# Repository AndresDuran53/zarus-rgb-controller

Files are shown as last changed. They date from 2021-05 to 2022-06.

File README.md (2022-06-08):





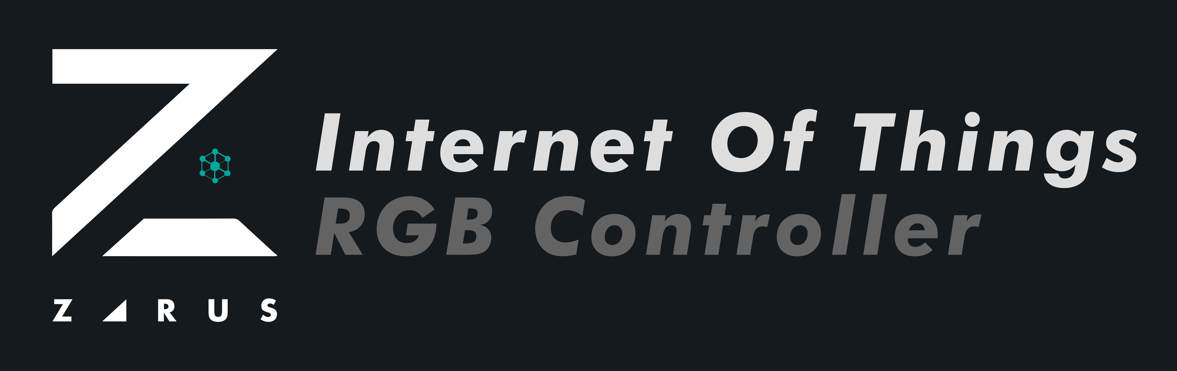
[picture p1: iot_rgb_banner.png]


# RGB Strip Controller for ESP8266 and ESP32
Control your rgb lights from your cell phone, using a website, an mqtt broker, or even the same remote control that came with the lights

Look at the [Zarus IoT Hub](https://github.com/AndresDuran53/zarus-iot-app) to get an easy way to connect to the devices without an IP.

## Quick Start
### Using Zarus IoT Hub application (Android only)
1. Download the Zarus IoT Hub application and open it.
2. Go to the *Devices* tab and click on *Find new device*.
3. Click on the device that you want to configure and wait until your phone connects.
4. Insert the name and password of your Home Wi-Fi, and click *Save configuration*.
5. Connect your phone again to your Home Wi-Fi and click *Refresh*.
6. Click *Scan network* and click the device that you want to add.
7. Now you can go to the *Home* tab and click the device to start using you new device.

For more information go to [Zarus IoT Hub](https://github.com/AndresDuran53/zarus-iot-app)

### Manually using a browser (IOS - Android - PC)
1. Go to your Wi-Fi configuration and look for a network named like: "rgb-light-xxxxxx"
2. Connect to that network with the password: *password123*
3. Open a browser (Google Chrome, Firefox, etc...) and go to *http://192.168.4.1*
4. On the WebPage click on *Settings* and *Device Settings*
5. Insert the SSID (name) and password of your Wi-Fi which you want the device be connected to, and click *Save/Guardar*.
6. Disconnect from the device network and connect to your Wi-Fi
7. You have to find which IP your device has in your network, you can use different applications for that.
8. Now that you have the IP of your device you just have to put that IP into the browser and you are going to be able to control the device.

## Create yours from scratch
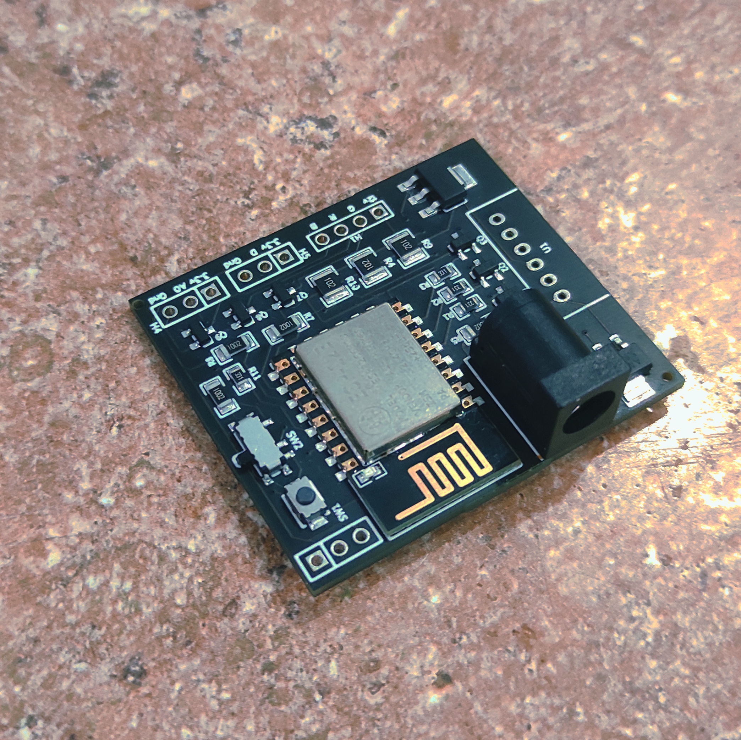
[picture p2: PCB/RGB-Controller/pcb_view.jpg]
RGB controller PCB view
[](PCB/RGB-Controller/pcb_view.jpg)

### PCB creation
You can find the Gerber, BOM, and PickAndPlace files in the [PCB/RGB-Controller](PCB/RGB-Controller) folder, to create your own PCB. Also you can import the hole folder into [EasyEDA](https://easyeda.com/es) to modify it yourself.

You only need to add a cable to connect to the RGB Leds (5050 Strip or NeoPixel, respective paths), and the InfraRed transistor if you wanted.

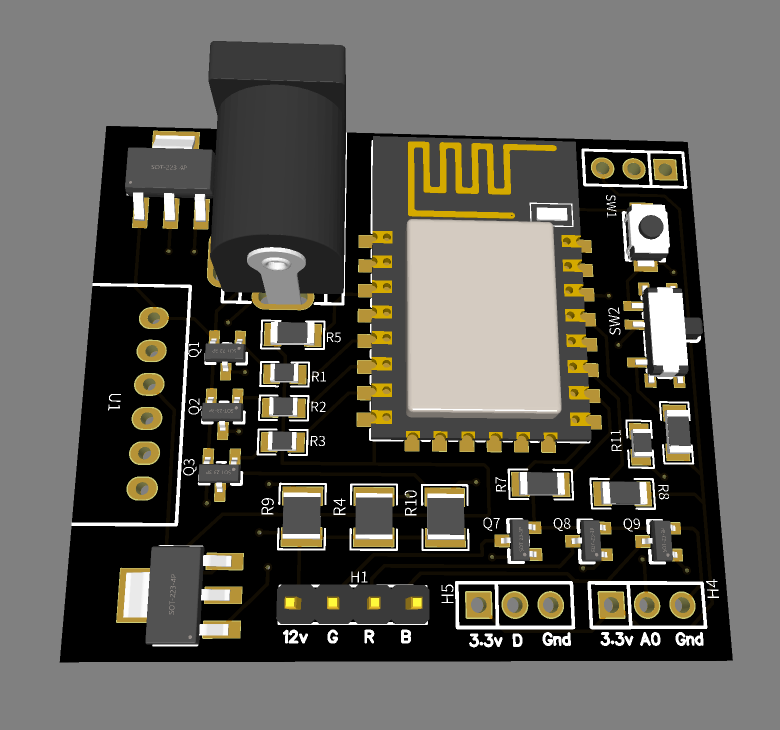
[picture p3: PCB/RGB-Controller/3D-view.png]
RGB controller PCB 3D view
[](PCB/RGB-Controller/3D-view.png)

### 3D Printing
In the folder [3D Desing](3D%20Desing) you can find the .stl file to print in any 3D printer and also a .FCStd file that you can use to modify the model using [Freecad](https://www.freecadweb.org/). Or if you wanted you can use the .gcode to just import to a printer.

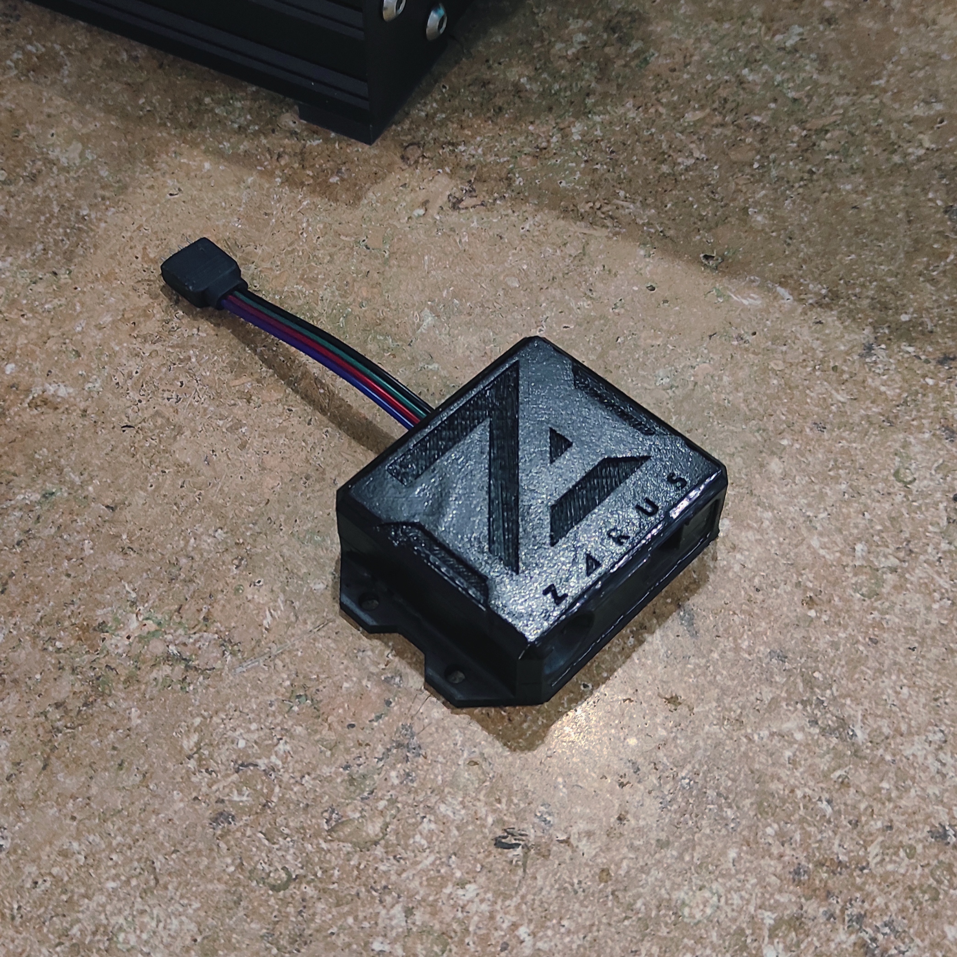
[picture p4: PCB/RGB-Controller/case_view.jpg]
RGB controller 3D case
[](PCB/RGB-Controller/case_view.jpg)

#### Parameters used for gcode
* Printer: Ender 3 Pro
* Material: PETG
* Heat Bed: Yes

### Compile using Arduino
1. Download the firmware in [RGB-Strip-Firmware](RGB-Strip-Firmware).
2. Open it in the Arduino IDE.
3. Import the libraries.
4. Upload the sketch.

#### Libraries and tools needed
Tools for upload files into the ESP device:
* ESP8266: [ESP8266fs](https://github.com/esp8266/arduino-esp8266fs-plugin/releases) | ESP32: [ESP32FS](https://github.com/me-no-dev/arduino-esp32fs-plugin/releases)

Libraries:
* [Network Controller](https://github.com/AndresDuran53/zarus-network-controller/)
* [IRremoteESP8266](https://github.com/crankyoldgit/IRremoteESP8266)

## TO-DO
- [ ] Check the IRremote library for ESP32

## License
Zarus RGB Controller is an open source code. All files are licenced under Creative Commons [Reconocimiento-NoComercial-CompartirIgual 4.0 Internacional](https://creativecommons.org/licenses/by-nc-sa/4.0/deed.es)

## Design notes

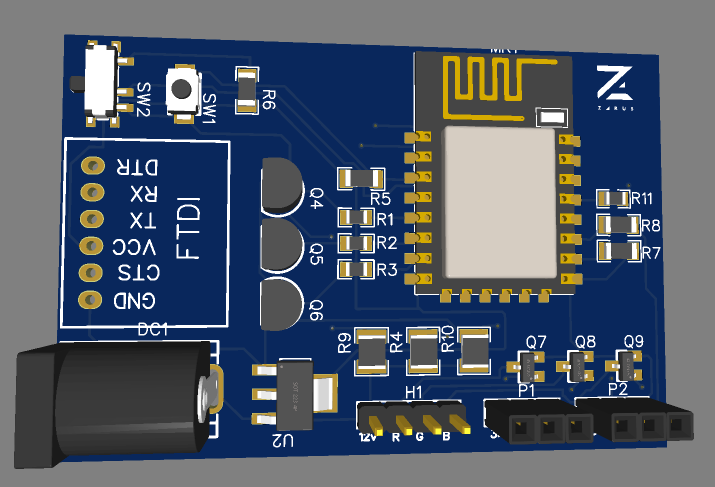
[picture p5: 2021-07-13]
PCB/nuevo/Screenshot 2021-06-23 192958.png

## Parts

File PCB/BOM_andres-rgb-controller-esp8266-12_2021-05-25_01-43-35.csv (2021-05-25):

ID | Name | Designator | Footprint | Quantity | Manufacturer Part | Manufacturer | Supplier | Supplier Part | _Price | JLCPCB Part Class
1 | IRFZ44VZSPBF | Q1,Q3,Q2 | D2PAK_L10.0-W9.0-P2.54-LS15.0-BR | 3 | IRFZ44VZSPBF | Infineon Technologies | LCSC | C520675 |  | Extended Part
2 | Header-Male-2.54_1x4_C59481 | H1 | HDR-TH_4P-P2.54-V | 1 | Headers Pins 1*4P | ReliaPro | LCSC | C59481
3 | SSSS811101 | SW2 | SW-SMD_SSSS811101 | 1 | SSSS811101 | ALPS | LCSC | C109335 |  | Extended Part
4 | AMS1117-3.3 | U2 | SOT-223-3_L6.5-W3.4-P2.30-LS7.0-BR | 1 | AMS1117-3.3 | AMS | LCSC | C6186 |  | Basic Part
5 | 10K | R7,R8,R5,R6 | R1206 | 4 | 1206W4F1002T5E | UniOhm | LCSC | C17902 |  | Basic Part
6 | TS-1185-C-A-A-A | SW1 | SW-SMD_L4.0-W3.0-LS5.0-EH | 1 | TS-1185-C-A-A-A | XKB Enterprise | LCSC | C561518 |  | Extended Part
7 | FTDI | U1 | FTDI_PROG | 1
8 | DC005-2.0MM | DC1 | DC-IN-TH_DC005 | 1 | DC005-2.0MM | SOFNG | LCSC | C111567
9 | ESP-12E | MK1 | WIFIM-SMD_ESP-12E | 1 | ESP-12E | Ai-Thinker | LCSC | C89297 |  | Extended Part

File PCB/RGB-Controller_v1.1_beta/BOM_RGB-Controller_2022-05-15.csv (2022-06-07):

ID | Name | Designator | Footprint | Quantity | Manufacturer Part | Manufacturer | Supplier | Supplier Part | Price
1 | LM7805S2/TR | U4 | TO-263-2_L10.0-W9.1-P5.08-LS15.2-BL | 1 | LM7805S2/TR | HGSEMI(华冠) | LCSC | C2902505 | 0.238
2 | TS-1185-C-A-A-A | SW1 | SW-SMD_L4.0-W3.0-LS5.0-EH | 1 | TS-1185-C-A-A-A | XKB Enterprise | LCSC | C561518 | 0.055
3 | TSOP38236 | LED1 | SENSOR-TG_TSOP38236 | 1 | TSOP38236 | VISHAY | LCSC | C5139 | 0.207
4 | BTC-MC5S-53 | USB1 | MICRO-USB-SMD_MICRO-USB-BTC-MC5S-43 | 1 | BTC-MC5S-53 | DGBZ(东莞博众) | LCSC | C2908216 | 0.031
5 | DC005-2.0MM | DC1 | DC-IN-TH_DC005 | 1 | DC005-2.0MM | SOFNG | LCSC | C111567 | 0.169
6 | 2n3904S-RTK/PS_C18536 | Q1,Q2,Q3 | SOT-23-3_L2.9-W1.3-P1.90-LS2.4-TR | 3 | 2n3904S-RTK/PS | KEC | LCSC | C18536 | 0.016
7 | AO3400A_C344010 | Q7,Q8,Q9 | SOT-23_L2.9-W1.3-P1.90-LS2.4-BR | 3 | AO3400A | Bourne Semicon (Shenzhen) | LCSC | C344010 | 0.055
8 | 330 | R1,R2,R3,R11 | R0805 | 4 | 0805W8J0331T5E | UniOhm | LCSC | C25306 | 0.002
9 | 10K | R5,R6,R7,R8 | R1206 | 4 | 1206W4F1002T5E | UniOhm | LCSC | C17902 | 0.005
10 | AMS1117-3.3 | U2 | SOT-223-3_L6.5-W3.4-P2.30-LS7.0-BR | 1 | AMS1117-3.3 | AMS | LCSC | C6186 | 0.146
11 | Header-Male-2.54_1x3 | H4,H5 | HEADER-MALE-2.54_1X3 | 2
12 | SSSS811101 | SW2 | SW-SMD_SSSS811101 | 1 | SSSS811101 | ALPS | LCSC | C109335 | 0.118
13 | 1K | R4,R9,R10 | R1210 | 3 | 1210W3J0102T5E | UniOhm | LCSC | C25681 | 0.008
14 | ESP-12E | MK1 | WIFIM-SMD_ESP-12E | 1 | ESP-12E | Ai-Thinker | LCSC | C89297 | 2.503
15 | USB-TTL-1sp | U3 | USB-TTL | 1

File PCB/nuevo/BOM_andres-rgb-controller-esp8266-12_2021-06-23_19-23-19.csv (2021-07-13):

ID | Name | Designator | Footprint | Quantity | Manufacturer Part | Manufacturer | Supplier | Supplier Part | JLCPCB Part Class
1 | 2N2222 | Q6,Q5,Q4 | TO-92-3_L4.9-W3.7-P1.27-L | 3 | 2N2222 | SEMTECH | LCSC | C118536 | Extended Part
2 | Header-Male-2.54_1x4_C59481 | H1 | HDR-TH_4P-P2.54-V | 1 | Headers Pins 1*4P | ReliaPro | LCSC | C59481
3 | SSSS811101 | SW2 | SW-SMD_SSSS811101 | 1 | SSSS811101 | ALPS | LCSC | C109335 | Extended Part
4 | AO3400A_C344010 | Q9,Q8,Q7 | SOT-23_L2.9-W1.3-P1.90-LS2.4-BR | 3 | AO3400A | Bourne Semicon (Shenzhen) | LCSC | C344010 | Extended Part
5 | AMS1117-3.3 | U2 | SOT-223-3_L6.5-W3.4-P2.30-LS7.0-BR | 1 | AMS1117-3.3 | AMS | LCSC | C6186 | Basic Part
6 | 10K | R7,R6,R5,R8 | R1206 | 4 | 1206W4F1002T5E | UniOhm | LCSC | C17902 | Basic Part
7 | 330 | R11,R1,R2,R3 | R0805 | 4 | 0805W8J0331T5E | UniOhm | LCSC | C25306 | Extended Part
8 | TS-1185-C-A-A-A | SW1 | SW-SMD_L4.0-W3.0-LS5.0-EH | 1 | TS-1185-C-A-A-A | XKB Enterprise | LCSC | C561518 | Extended Part
9 | FTDI | U1 | FTDI_PROG | 1
10 | ws2812 | P1 | HDR-TH_3P-P2.54-V-F | 1 | Header-Female-2.54_1x3 | Boom Precision Elec | LCSC | C146243 | Extended Part
11 | ADC | P2 | HDR-TH_3P-P2.54-V-F | 1 | Header-Female-2.54_1x3 | Boom Precision Elec | LCSC | C146243 | Extended Part
12 | DC005-2.0MM | DC1 | DC-IN-TH_DC005 | 1 | DC005-2.0MM | SOFNG | LCSC | C111567
13 | 1K | R4,R9,R10 | R1210 | 3 | 1210W3J0102T5E | UniOhm | LCSC | C25681 | Extended Part
14 | ESP-12E | MK1 | WIFIM-SMD_ESP-12E | 1 | ESP-12E | Ai-Thinker | LCSC | C89297 | Extended Part

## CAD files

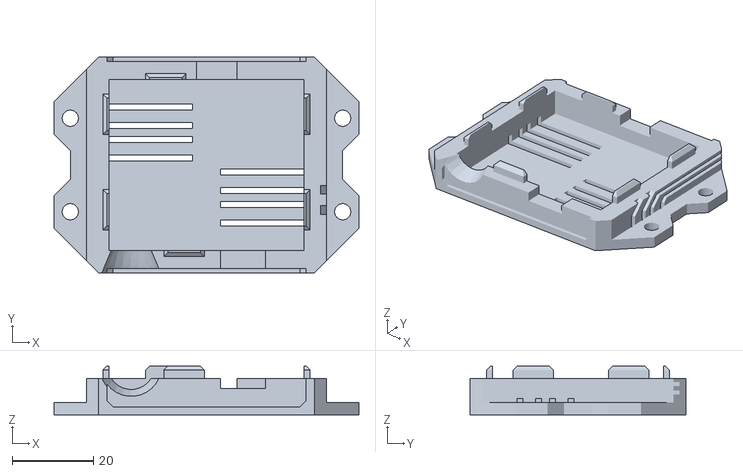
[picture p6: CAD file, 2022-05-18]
3D Desing/bot.stl
75.0 x 53.0 x 12.0

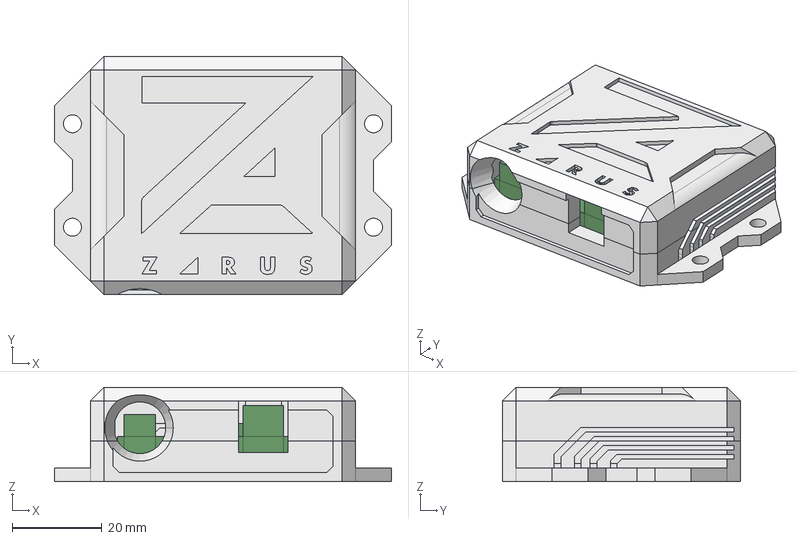
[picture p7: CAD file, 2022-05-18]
3D Desing/v1.0/case.FCStd
75.0 x 53.0 x 21.0 mm
PCB
Espaciador
Top_case
Bot_case

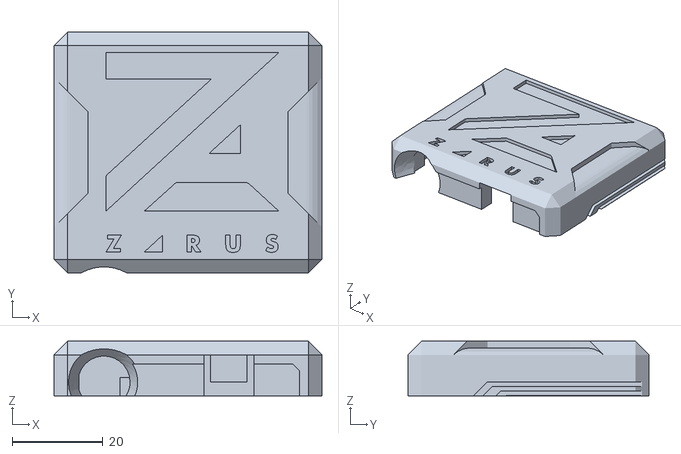
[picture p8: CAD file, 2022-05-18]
3D Desing/top.stl
59.0 x 53.0 x 12.0

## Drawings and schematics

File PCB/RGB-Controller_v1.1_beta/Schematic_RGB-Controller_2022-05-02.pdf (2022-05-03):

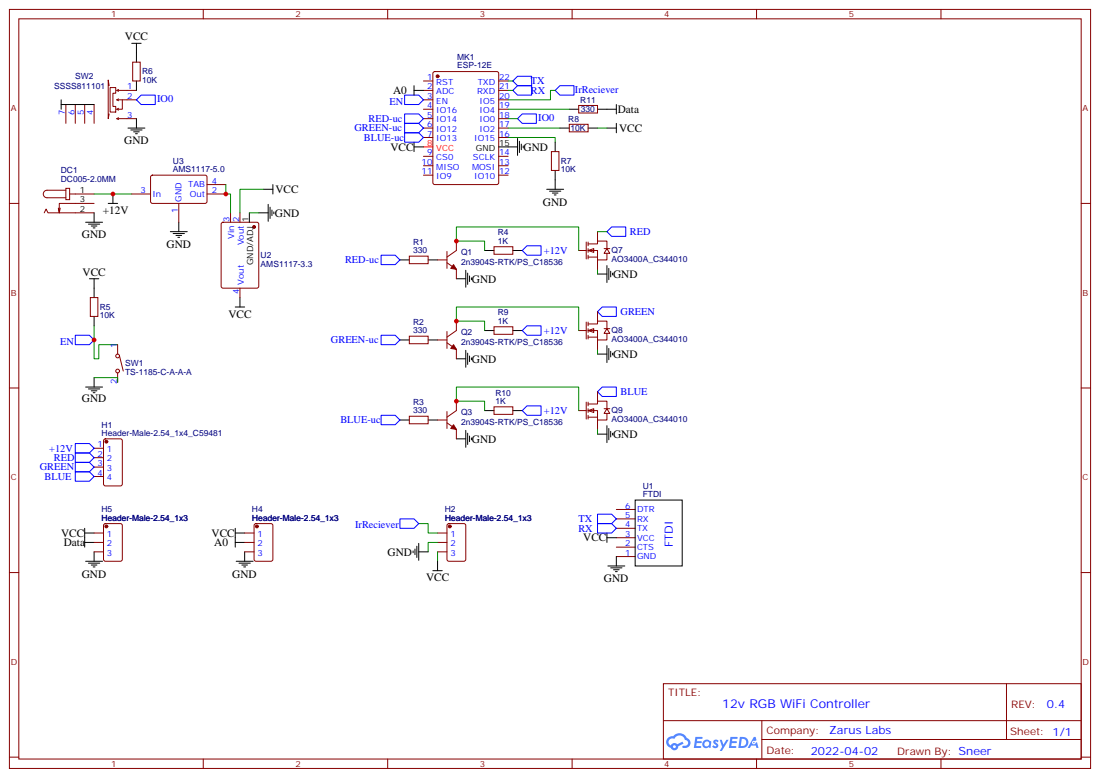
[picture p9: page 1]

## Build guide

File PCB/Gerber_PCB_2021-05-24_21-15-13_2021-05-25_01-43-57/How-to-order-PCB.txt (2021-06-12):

How to Order PCB

Please refer to:
https://docs.easyeda.com/en/PCB/Order-PCB

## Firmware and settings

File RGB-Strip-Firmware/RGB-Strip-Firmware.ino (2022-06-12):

#include <IoTController.h>
#include <IRremoteESP8266.h>
#include <IRrecv.h>
#include <IRutils.h>
#include "RgbRemote.h"

#define RED_PIN                 12
#define GREEN_PIN               14
#define BLUE_PIN                13
#define MAX_BRIGHTNESS          100

String deviceType = "rgb-light";
String deviceToken = "zzz999";
uint8_t consoleLevel = 3;

const uint16_t kRecvPin = 5;
unsigned long key_value = 0;
IRrecv irrecv(kRecvPin);
decode_results results;
RgbRemote rgbRemote(0);

//-----Variables Definition-----//
int actualBrightness = MAX_BRIGHTNESS;
String actualHexValue = "#000000";
int display_step = 0;
int display_mode = 0;
String hexValueTemp = actualHexValue;
int brightnessTemp = actualBrightness;

void setColorFromHex(String hexValue,int brightness=-1);

void configGPIO() {
  pinMode(RED_PIN, OUTPUT);
  pinMode(GREEN_PIN, OUTPUT);
  pinMode(BLUE_PIN, OUTPUT);
  pinMode(kRecvPin, INPUT);
}

void startLights() {
  setColorFromRGB(255, 0, 0, MAX_BRIGHTNESS);
  delay(150);
  setColorFromRGB(0, 255, 0, MAX_BRIGHTNESS);
  delay(150);
  setColorFromRGB(0, 0, 255, MAX_BRIGHTNESS);
  delay(150);
  setColorFromRGB(255, 255, 255, MAX_BRIGHTNESS);
  delay(150);
  setColorFromRGB(0, 0, 0, 0);
}

void setColorFromRGB(int r, int g, int b, int brightness) {
  Logger::log("Setting RGB Value: " + String(r) + String(g) + String(b), Logger::DEBUG_LOG);
  Logger::log("Passed Brightness: " + String(brightness), Logger::DEBUG_LOG);
  r = map((r * (brightness / 100.0)), 255, 0, 0, 1024);
  g = map((g * (brightness / 100.0)), 255, 0, 0, 1024);
  b = map((b * (brightness / 100.0)), 255, 0, 0, 1024);
  int r_aux = min(1024, r);
  int g_aux = min(1024, g);
  int b_aux = min(1024, b);
  analogWrite(RED_PIN, r_aux);
  analogWrite(GREEN_PIN, g_aux);
  analogWrite(BLUE_PIN, b_aux);
}

String getRGBStringFromHex(String hexValue){
  int number = (int) strtol( &hexValue[1], NULL, 16);
  int r = number >> 16;
  int g = number >> 8 & 0xFF;
  int b = number & 0xFF;
  return String(r)+","+String(g)+","+String(b)+",";
}

void setColorFromHex(String hexValue,int brightness) {
  if(brightness==-1) brightness = actualBrightness;
  actualHexValue = hexValue;
  Logger::log("Setting Hex Value: " + hexValue, Logger::DEBUG_LOG);
  Logger::log("Actual Brightness: " + String(actualBrightness), Logger::DEBUG_LOG);
  int number = (int) strtol( &hexValue[1], NULL, 16);
  int r = number >> 16;
  int g = number >> 8 & 0xFF;
  int b = number & 0xFF;
  setColorFromRGB(r, g, b, brightness);
}

void setColorHexFromMqtt(String hexValue){
  setColorFromHex(hexValue,actualBrightness);
  String rgbv = getRGBStringFromHex(hexValue);
  String jsonResponse = "{\"CID\":\"0\",\"rgbv\":\""+rgbv+"\"}";
  IoTController::sendMqttMessage(jsonResponse);
}

String rgbToHex(int red, int green, int blue) {
  if(red>=0 && green>=0 && blue>=0 && red<=255,green<=255,blue<=255){
    char hex[8] = {0};
    sprintf(hex, "#%02X%02X%02X", red, green, blue);
    hex[7] = '\0';
    String hexValue = String(hex);
    return hexValue;
  }
  else return actualHexValue;
}

String rgbStringToHex(String rgbValue){
  int valuesRGB[3];
  String valueAux = rgbValue;
  int index;
  String redValue;
  if(rgbValue.length()<5 || rgbValue.length()>11){
    return actualHexValue;
  }
  for(int i = 0; i<3; i++){
    index = valueAux.indexOf(',');
    valuesRGB[i] = valueAux.substring(0,index).toInt();
    valueAux = valueAux.substring(index+1,valueAux.length());
  }
  return rgbToHex(valuesRGB[0],valuesRGB[1],valuesRGB[2]);
}

void setColorFromRgbString(String rgbValue){
  String hexvalue = rgbStringToHex(rgbValue);
  setColorFromHex(hexvalue);
}

int mapBrightness(int brightness){
  int newValueMapped = max(0, min(MAX_BRIGHTNESS, brightness));
  Logger::log("newValueMapped" + String(newValueMapped), Logger::DEBUG_LOG);
  return newValueMapped;
}

void setActualBrightness(String newValue) {
  Logger::log("Setting new Brightness: " + String(newValue), Logger::DEBUG_LOG);
  int newValueMapped = newValue.toInt();
  actualBrightness = mapBrightness(newValueMapped);
  setColorFromHex(actualHexValue);
}

//Animations
void stepAnimation() {
  switch (display_mode) {
    case 1:
      flashEffect();
      setColorFromHex(hexValueTemp);
      break;
    case 2:
      strobeEffect();
      setColorFromHex(actualHexValue,brightnessTemp);
      break;
    case 3:
      fadeEffect();
      setColorFromHex(hexValueTemp);
      break;
    case 4:
      smoothEffect();
      setColorFromHex(hexValueTemp);
      break;
    case 5:
      breathEffect();
      setColorFromHex(actualHexValue,brightnessTemp);
      break;
    case 6:
      attackEffect();
      setColorFromHex(actualHexValue,brightnessTemp);
      break;
    case 7:
      nightClubEffect();
      setColorFromHex(hexValueTemp);
      break;
    default:
      break;
  }
  display_step++;
}

void setEffect(String newValue) {
  display_mode = newValue.toInt();
}

void flashEffect() {
  int WheelPos = (display_step % 255);
  int WheelPos2 = (display_step % 35);
  int red = 0;
  int green = 0;
  int blue = 0;
  WheelPos = 255 - WheelPos;
  if (WheelPos < 85) {
    red = 255 - WheelPos * 3;
    green = 0;
    blue = WheelPos * 3;
  }
  else if (WheelPos < 170) {
    WheelPos -= 85;
    red = 0;
    green = WheelPos * 3;
    blue = 255 - WheelPos * 3;
  }
  else {
    WheelPos -= 170;
    red = WheelPos * 3;
    green = 255 - WheelPos * 3;
    blue = 0;
  }
  String hexValue = rgbToHex(red, green, blue);
  if (WheelPos2 == 0) {
    hexValueTemp = hexValue;
  }
} //flashEffect()

void strobeEffect() {
  int WheelPos = (display_step % 256) / 16;
  if (WheelPos % 2 == 0) {
    brightnessTemp = MAX_BRIGHTNESS;
  }
  else {
    brightnessTemp = 0;
  }
} //strobeEffect()

void fadeEffect() {
  int WheelPos = display_step % 255;
  int red = 0;
  int green = 0;
  int blue = 0;
  WheelPos = 255 - WheelPos;
  if (WheelPos < 85) {
    red = 255 - WheelPos * 3;
    green = 0;
    blue = WheelPos * 3;
  }
  else if (WheelPos < 170) {
    WheelPos -= 85;
    red = 0;
    green = WheelPos * 3;
    blue = 255 - WheelPos * 3;
  }
  else {
    WheelPos -= 170;
    red = WheelPos * 3;
    green = 255 - WheelPos * 3;
    blue = 0;
  }
  String hexValue = rgbToHex(red, green, blue);
  hexValueTemp = hexValue;
} //fadeEffect()

void smoothEffect() {
  int WheelPos = (display_step % 1024) / 4;
  int red = 0;
  int green = 0;
  int blue = 0;
  WheelPos = 255 - WheelPos;
  if (WheelPos < 85) {
    red = 255 - WheelPos * 3;
    green = 0;
    blue = WheelPos * 3;
  }
  else if (WheelPos < 170) {
    WheelPos -= 85;
    red = 0;
    green = WheelPos * 3;
    blue = 255 - WheelPos * 3;
  }
  else {
    WheelPos -= 170;
    red = WheelPos * 3;
    green = 255 - WheelPos * 3;
    blue = 0;
  }
  String hexValue = rgbToHex(red, green, blue);
  hexValueTemp = hexValue;
} //smoothEffect()

void breathEffect() {
  int WheelPos = (display_step % 256);
  int WheelPos2 = WheelPos / 4;
  if (WheelPos > 167) {
    WheelPos = 251 - WheelPos + 42;
  }
  WheelPos = map(WheelPos, 42, 125, 0, MAX_BRIGHTNESS);
  int brightnessAux = mapBrightness(WheelPos);
  if (WheelPos2 % 2 == 0) {
    brightnessTemp = brightnessAux;
  }
} //strobeEffect()

void attackEffect() {
  int WheelPos = (display_step % 64)*4;
  int WheelPos2 = WheelPos / 4;
  WheelPos = map(WheelPos, 42, 125, 100, 0);
  int brightnessAux = mapBrightness(WheelPos);
  if (WheelPos2 % 2 == 0) {
    brightnessTemp = brightnessAux;
  }
} //strobeEffect()

void nightClubEffect() {
  int WheelPos = (display_step % 64) * 4;
  int red = 0;
  int green = 0;
  int blue = 0;
  WheelPos = 255 - WheelPos;
  if (WheelPos < 85) {
    red = 255 - WheelPos * 3;
    green = 0;
    blue = WheelPos * 3;
  }
  else if (WheelPos < 170) {
    WheelPos -= 85;
    red = 0;
    green = WheelPos * 3;
    blue = 255 - WheelPos * 3;
  }
  else {
    WheelPos -= 170;
    red = WheelPos * 3;
    green = 255 - WheelPos * 3;
    blue = 0;
  }
  String hexValue = rgbToHex(red, green, blue);
  hexValueTemp = hexValue;
} //nightClubEffect()

//---------------------------------//

void verifyIRrecieved(String value) {
  if (value == "ON") {
    IoTController::changeStoredValue("dsmd","0");
    IoTController::changeStoredValue("lhbr","100");
  }
  else if (value == "OFF") {
    IoTController::changeStoredValue("dsmd","0");
    IoTController::changeStoredValue("lhbr","0");
  }
  else if (value == "BRILLO_ARRIBA") {
    int actualBrightnessAux = min(MAX_BRIGHTNESS, actualBrightness + 10);
    IoTController::changeStoredValue("lhbr",String(actualBrightnessAux));
  }
  else if (value == "BRILLO_ABAJO") {

    int actualBrightnessAux = max(0, actualBrightness - 10);
    IoTController::changeStoredValue("lhbr",String(actualBrightnessAux));
  }
  else if (value == "FLASH") {
    IoTController::changeStoredValue("dsmd","1");
  }
  else if (value == "STROBE") {
    IoTController::changeStoredValue("dsmd","2");
  }
  else if (value == "FADE") {
    IoTController::changeStoredValue("dsmd","3");
  }
  else if (value == "SMOOTH") {
    IoTController::changeStoredValue("dsmd","4");
  }
  else if (value == "Ninguno") {return;}
  else {
    IoTController::changeStoredValue("dsmd","0");
    IoTController::changeStoredValue("rgbh",value);
  }
}

void checkIRrecieved() {
  if (irrecv.decode(&results)) {
    String valueRecieved = rgbRemote.getIRDecodeValue(results.value);
    Logger::log("New IR value recieved: " + String(valueRecieved), Logger::DEBUG_LOG);
    verifyIRrecieved(valueRecieved);
    irrecv.resume();
  }
}

void IoTConfig() {
  IoTController::addTimer(100, checkIRrecieved);
  IoTController::addTimer(20, stepAnimation);
  IoTController::setup(deviceType, consoleLevel, deviceToken);
  IoTController::createStoredData("rgb_color_hex", "rgbh", 8, "#000000", "String", [](String hexValue) {
    setColorHexFromMqtt(hexValue);
  });
  IoTController::createStoredData("rgb_color_value", "rgbv", 12, "0,0,0", "String", [](String rgbValue) {
    setColorFromRgbString(rgbValue);
  });
  IoTController::createStoredData("actual_brightness", "lhbr", 4, String(actualBrightness), "int", [](String newValue) {
    setActualBrightness(newValue);
  });
  IoTController::createStoredData("display_mode", "dsmd", 2, "0", "String", [](String newValue) {
    setEffect(newValue);
  });
  IoTController::init();
}

void setup() {
  irrecv.enableIRIn();
  IoTConfig();
  configGPIO();
  startLights();
}

void loop() {
  IoTController::loop();
}

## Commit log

2021-05-25 Adding PCB files
    [BOM_andres-rgb-controller-esp8266-12_2021-05-25_01-43-35.csv, PickAndPlace_PCB_2021-05-24_21-15-13_2021-05-25_01-44-03.csv]
2021-06-12 -Adding gerber Files -Adding 3d Files -Adding test code
    [Bot.stl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]
2021-06-12 --Using jquery local --UI improved
    [Bot.stl, Top.stl, case.FCStd]
2021-06-13 adding color picker button
2021-06-13 functional Wheel of Colors
2021-07-13 PCB files edit
    [BOM_andres-rgb-controller-esp8266-12_2021-05-25_01-43-35.csv, BOM_andres-rgb-controller-esp8266-12_2021-06-23_19-23-19.csv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]
2022-05-03 V0.4 Fabricated
    [BOM_RGB-Controller_2022-05-02.csv, BOM_andres-rgb-controller-esp8266-12_2021-05-25_01-43-35.csv, BOM_andres-rgb-controller-esp8266-12_2021-06-23_19-23-19.csv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]
2022-05-13 adding new 3d files for the pcb 1.0v
    [Top.stl, bot.stl, case.FCStd]
2022-05-13 updating desing
    [case.FCStd]
2022-05-13 adding printed version of the circuit
    [BOM_RGB-Controller_2022-05-02.csv, PickAndPlace_PCB_2021-06-23_18-43-15_2021-06-23_19-29-14_2022-05-02.csv]
2022-05-13 updating pcb
2022-05-18 Improving Desing 3D
    [BOM_RGB-Controller_2022-05-02.csv, BOM_RGB-Controller_2022-05-15.csv, PickAndPlace_PCB_2021-06-23_18-43-15_2021-06-23_19-29-14_2022-05-02.csv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]
2022-05-18 rename old version folder
    [Bot.stl, Top.stl, case.FCStd]
2022-05-31 adding device option on deviceSettings.html
2022-06-01 Version 1.0
    [BOM_RGB-Controller_2022-05-02.csv, BOM_RGB-Controller_2022-05-15.csv, BOM_andres-rgb-controller-esp8266-12_2021-05-25_01-43-35.csv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]
2022-06-07 improving pcb
    [BOM_RGB-Controller_2022-05-15.csv, PickAndPlace_PCB_2021-06-23_18-43-15_2021-06-23_19-29-14_2022-05-15.csv]

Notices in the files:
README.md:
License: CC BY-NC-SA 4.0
